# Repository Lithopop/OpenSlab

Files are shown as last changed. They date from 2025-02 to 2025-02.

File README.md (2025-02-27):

# OpenSlab
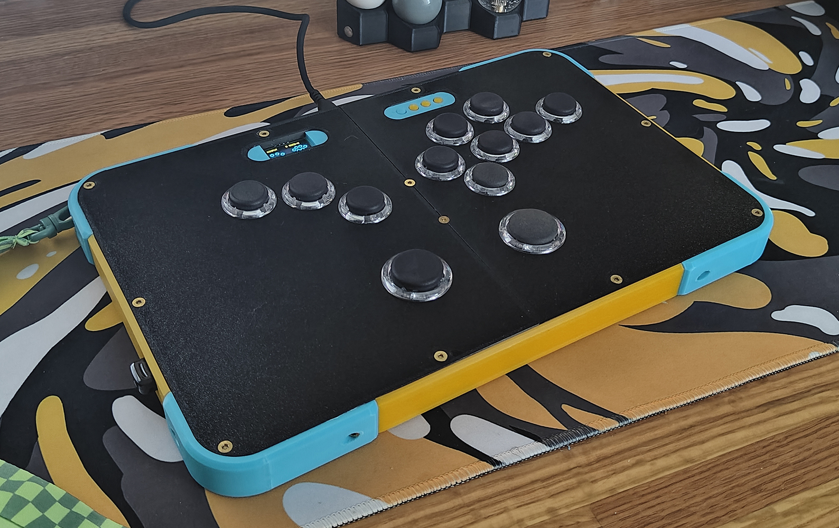
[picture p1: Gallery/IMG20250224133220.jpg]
Openslab image

flexible and rugged open source low profile leverless controller 

Openslab is an attempt to bridge the gap between the mod-ability of traditional fight sticks and the form factor of PCB based leverless designs.

Print Instructions
-----------
Frame Common Files - Mandatory files regardless of layout or plate materials. There are options for both USB C and B top walls here, and the corners are mirrored, allowing you to swap them around and put a shoulder strap or lanyard on any side, or just print 2 copies of the bottom corners if you don't want the mount points. Also note that there are arrows on the inside of all of the frame wall pieces. these should print facing up, because the top face is slightly thicker  than the bottom (4mm top, 3mm bottom) Also included is a cable cover to tidy up some wiring.

3d print plates common files - this is a collection of print files needed for a fully 3d printed leveless fight stick, that include the center brace (not part of the walls section because it's not used in acrylic builds), the assemblies f to house electronic components (gpio and display), the buttons for the GPIO which will need you to print 4 copies, and the 2 bottom panels

Fauxlix, Fauxir, Fega p2, 6 god , and 6 ERGOd top panels - A collection of layouts that will house your arcade buttons and RP2040. these are just Viewlix, Noir, Sega p2, 6 Gawd, and 6 ERGOd(my personal ergo 6 gawd format) scaled down to use primarily 24mm buttons and will use 30mm as thumb buttons. 

Plates - Cut acrylic/steel Ergod (UNTESTED) - This are just files for acrylic and steel cut parts for the tops and bottom of the fight stick, please note that this includes some 3d printed parts because the electronics housings and RP2040 mount are different. 

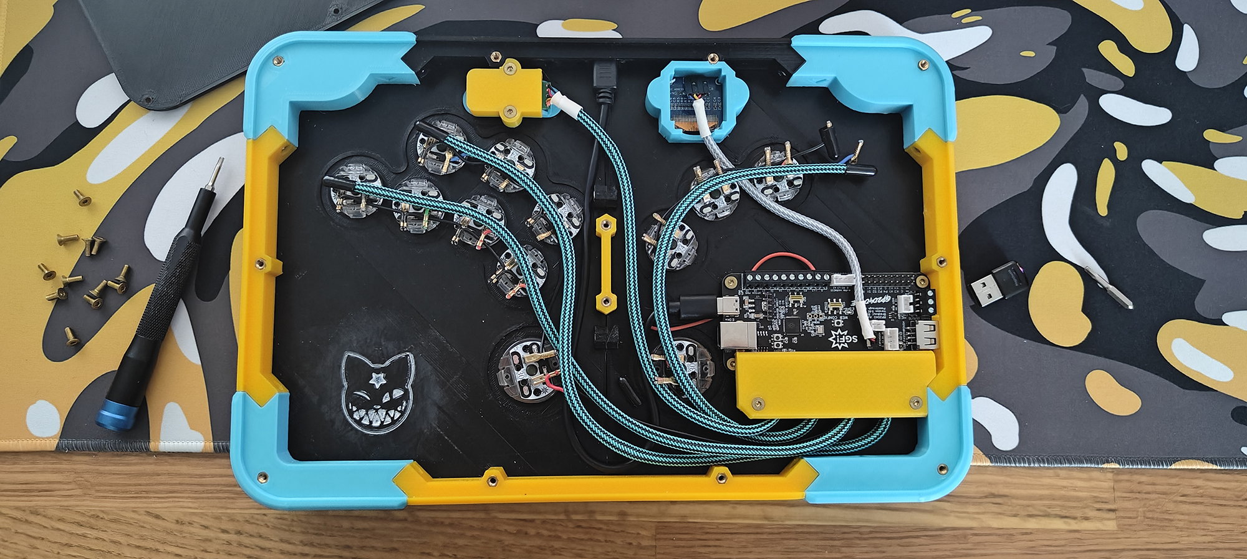
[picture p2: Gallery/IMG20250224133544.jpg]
Openslab internals


Construction process
-------------
- Build Frame
- Mount top face
- Flip upside and down insert buttons, put electronics in housings and then slot them into the top face plate (they press fit between the top and bottom faces), wire everything, add RP mount lid (cable cover)
- mount bottom plate
- set up/config RP2040
- Plug in
- enjoy?
- Give feedback (Optional)

Plexi build hardware needed/electronics needed
-----------
10 x 15mm m3 standoff

34 x 8mm flat head m3 hex 

14 x m3 nut

8 x 16mm cup head m3 hex

30 cm panel mount USB-B to 5 pin dupont or USB Type C 3.1Panel Mount Adapter Cable

Choice of low profile buttons

.96 inch Display

gpio Button Module Push Button Board

RP2040

Full 3d Print build hardware/electronics needed
-----------
12 x 15mm m3 standoff

34 x 8mm flat head m3 hex 

10 x m3 nut

8 x 16mm cup head m3 hex

30 cm panel mount USB-B to 5 pin dupont or USB Type C 3.1Panel Mount Adapter Cable

Choice of low profile buttons

.96 inch Display

gpio Button Module Push Button Board

RP2040

Electronics links
-----------
0.96 Inch OLED Module 12864 128x64 Yellow Blue SSD1306 Driver I2C Serial Self-Luminous Display Board - https://www.amazon.com/gp/product/B072Q2X2LL?ie=UTF8&psc=1 (You can probabkly find other colors, tollerances may vary this is just what I prototyped with)

Button Array Button Module Electronic Components gpio Button Module Push Button Board - https://www.amazon.com/gp/product/B0C9P8H3YZ?ie=UTF8&psc=1

Panel Mount USB 2.0 B Cable USB B Female to 5 pin Female Dupont Motherboard USB Header Cable - https://www.amazon.com/gp/product/B07DNN94JD?ie=UTF8&psc=1

USB Type C 3.1Panel Mount Adapter Cable USB-C 3.1 Gen2 10Gbps Male to USB C Female Panel Mount Screw Cable - https://www.amazon.com/gp/product/B0CCRXF1N7?ie=UTF8&psc=1

RP2040 Advanced breakout board (If you can't find one of these from a small business, what are you doing here?)

Low Profile Arcade/fightstick Buttons (Tested with Monkey Butts and Sitongs) 

Hardware links (Please note, that I used brass, you can use alternatives)
-----------
15mm m3 standoff - https://www.amazon.com/gp/product/B07H9VJ29Q?ie=UTF8&psc=1

8mm flat head m3 hex - https://www.amazon.com/gp/product/B0BP6B8CRD?ie=UTF8&th=1

m3 nut

16mm cup head m3 hex - https://www.amazon.com/gp/product/B0C7BYKWZF?ie=UTF8&th=1

While it's not necessary, Donations are always appreciated and help speed up revisions and development of other projects. (and/or farther the endeavor to push my little girl into real video games and get her away from tablet based subway surfers clones)

https://www.paypal.com/paypalme/williamthomas157

Feel free to contact me on discord with any comments, questions or suggestions.

riverbottom

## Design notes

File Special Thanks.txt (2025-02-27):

Special thanks to:

JayFree and greendusk for beta prints and testing.

InfraredAces for the fantastic idea of making my documentation "more IKEA".

Xanibunib for finding an error in my clean step file with Bottom print plate b.

OpenStickCommunity and /r/Fightsticks Discord for support and feedback.

Noblix, for the idea to eliminate the 10mm bolts.

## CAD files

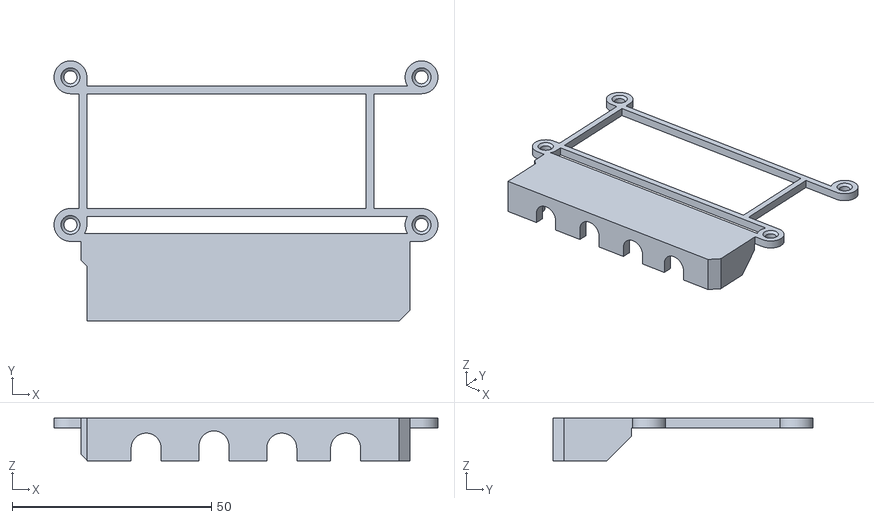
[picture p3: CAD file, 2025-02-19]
Print-Build Files/! Experimental/Acrylic Steel Plates ERGOd/RP mount.stl
96.2 x 65.2 x 10.7

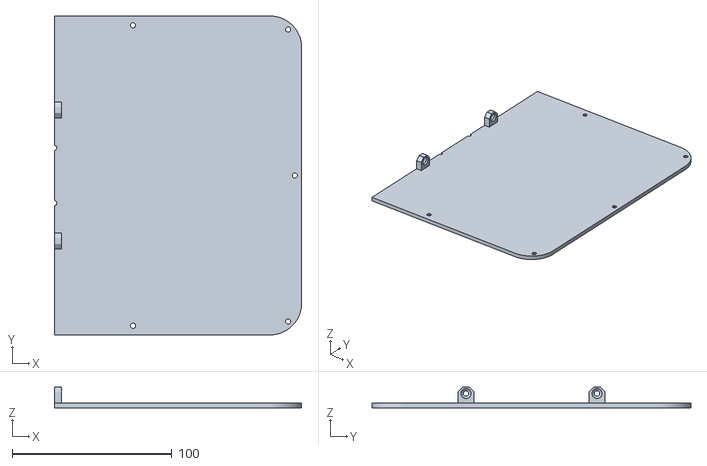
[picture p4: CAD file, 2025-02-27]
Print-Build Files/- 3D Print Plates Common Files/bottom PRINT a.stl
154.8 x 199.6 x 13.0

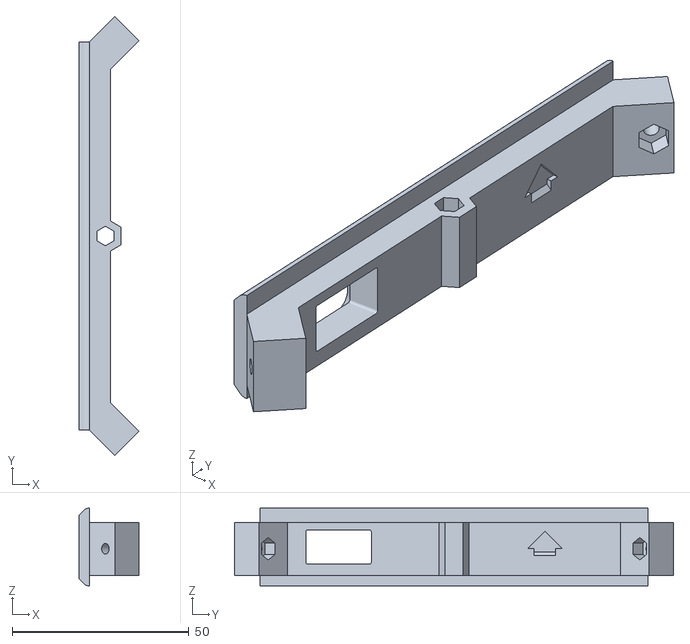
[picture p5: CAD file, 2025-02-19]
Print-Build Files/- Frame Common Files/Pass thorugh wall.stl
17.0 x 124.3 x 22.0

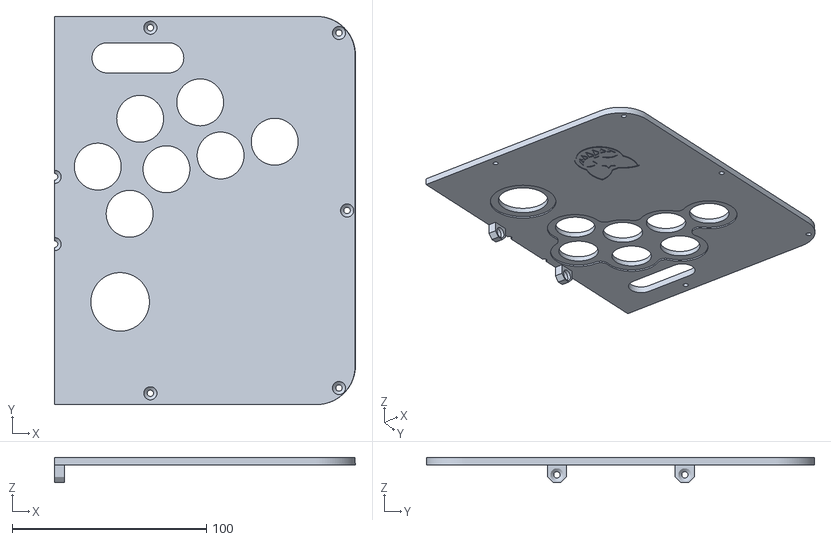
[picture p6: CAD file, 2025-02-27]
Print-Build Files/6 ERGOd/Right 6 ERGOd.stl
154.8 x 199.6 x 13.0

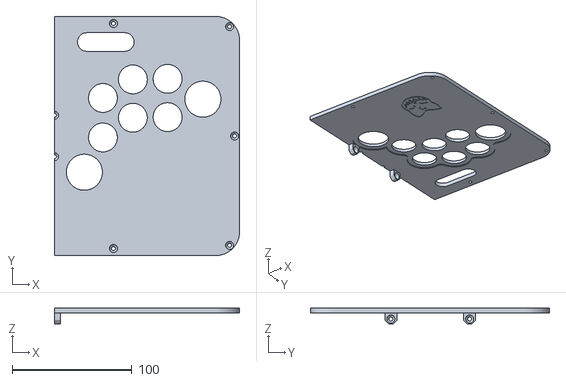
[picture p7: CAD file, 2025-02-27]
Print-Build Files/6 Fawd/Right 6 Gawd.stl
154.6 x 199.6 x 13.0

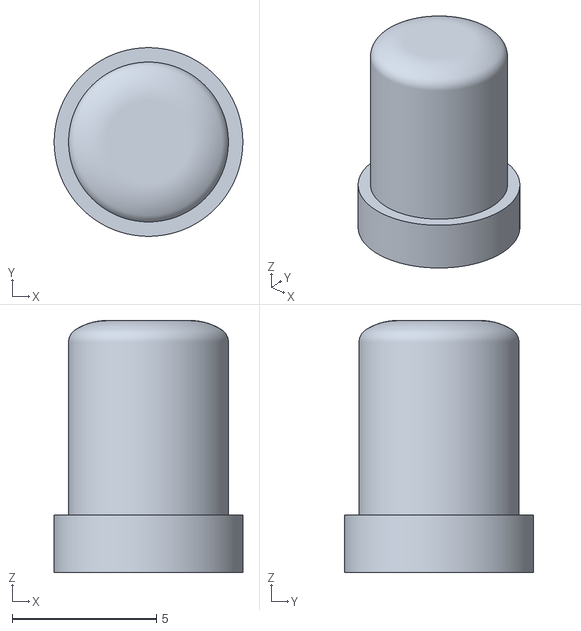
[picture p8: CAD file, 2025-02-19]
Print-Build Files/! Experimental/Acrylic Steel Plates ERGOd/button round for plexi.stl
6.55 x 6.55 x 8.75

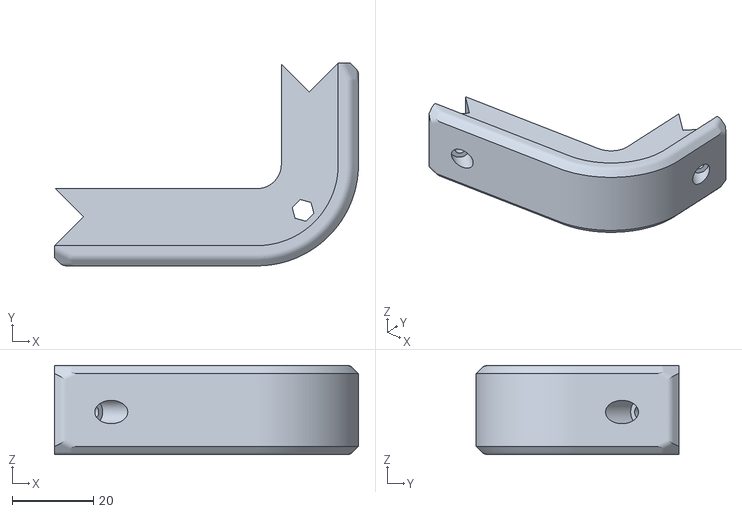
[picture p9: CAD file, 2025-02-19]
Print-Build Files/- Frame Common Files/Bottom Right Corner.stl
75.0 x 50.0 x 22.0

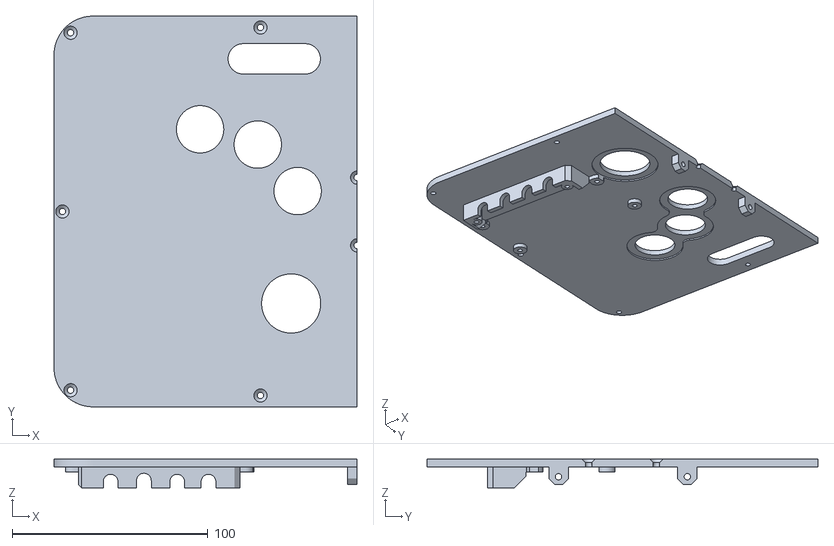
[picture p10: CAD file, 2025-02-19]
Print-Build Files/6 ERGOd/Left 6 ERGOd.stl
154.8 x 199.6 x 14.7

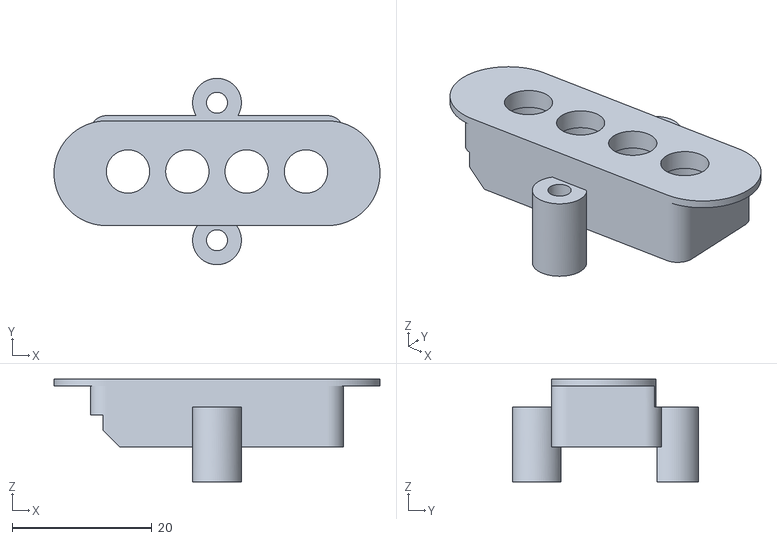
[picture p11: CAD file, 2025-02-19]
Print-Build Files/! Experimental/Acrylic Steel Plates ERGOd/aux frame top plexi.stl
46.7 x 26.7 x 14.8

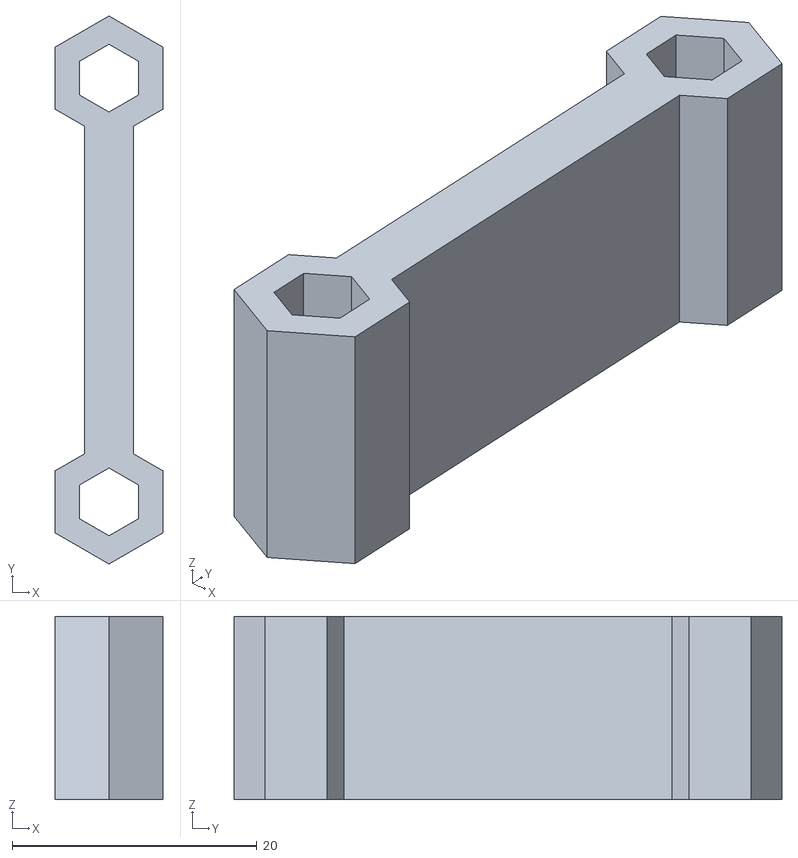
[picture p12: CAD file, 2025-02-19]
Print-Build Files/- 3D Print Plates Common Files/Mid Support.stl
8.80 x 44.8 x 15.0

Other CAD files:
Print-Build Files/Fauxir/right Fauxlir.stl
Print-Build Files/Fauxlix/right Fauxlix.stl
Print-Build Files/Fega P2/right Fega P2.stl
Print-Build Files/- 3D Print Plates Common Files/bottom PRINT b.stl
Print-Build Files/6 Fawd/Left 6 Gawd.stl
Print-Build Files/Fauxir/Left Fauxir.stl
Print-Build Files/Fauxlix/Left Fauxlix.stl
Print-Build Files/Fega P2/Left Fega P2.stl
Print-Build Files/! Experimental/Acrylic Steel Plates ERGOd/Screen holder.stl
Print-Build Files/! Experimental/Acrylic Steel Plates ERGOd/Steel Top.stl
Print-Build Files/! Experimental/Acrylic Steel Plates ERGOd/aux frame bottom plexi.stl
Print-Build Files/! Experimental/Acrylic Steel Plates ERGOd/bottom plexi.stl
Print-Build Files/! Experimental/Acrylic Steel Plates ERGOd/plexi Top.stl
Print-Build Files/- 3D Print Plates Common Files/Screen holder.stl
Print-Build Files/- 3D Print Plates Common Files/aux frame bottom.stl
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

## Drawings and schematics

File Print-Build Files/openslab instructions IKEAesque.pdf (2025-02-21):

1

2

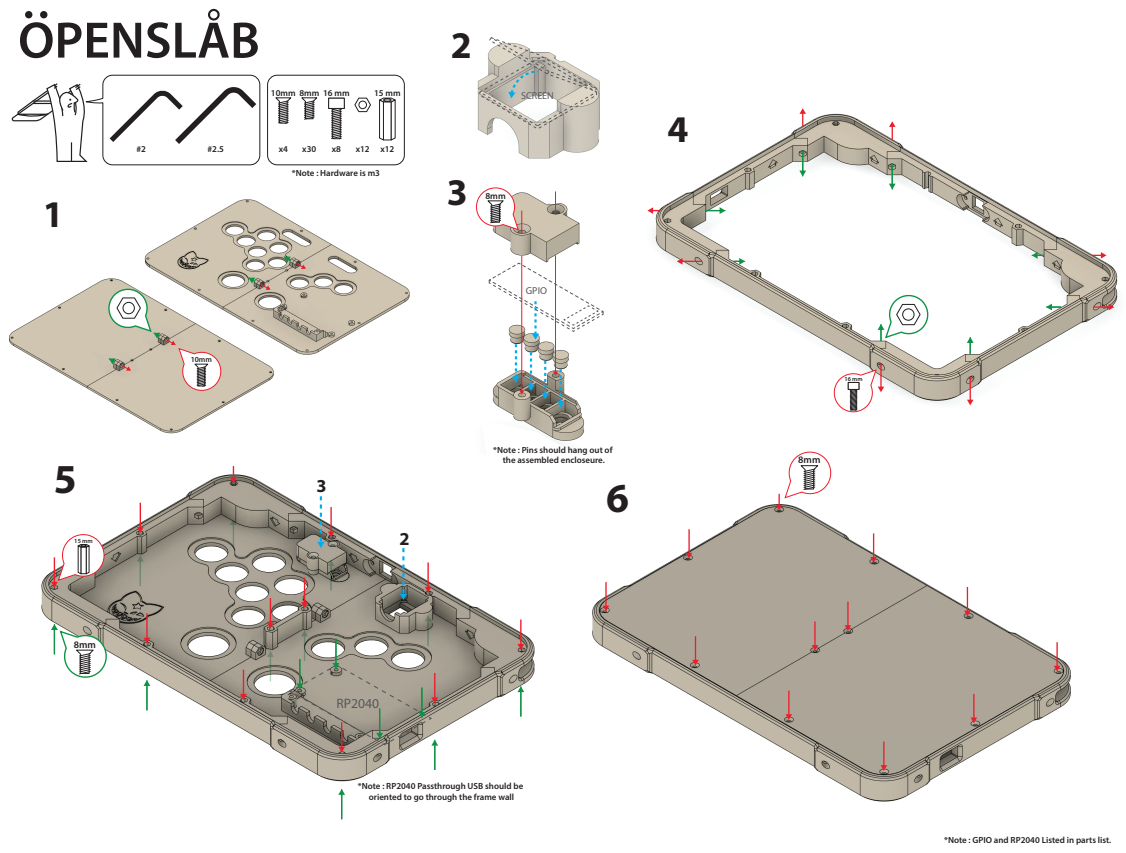
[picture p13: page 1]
SCREEN; OPENSLAB 10mm 8mm; GPIO

*Note : Hardware is m3

*Note : Pins should hang out of
the assembled encloseure.

*Note : RP2040 Passthrough USB should be
oriented to go through the frame wall

*Note : GPIO and RP2040 Listed in parts list.

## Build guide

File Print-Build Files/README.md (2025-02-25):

# OpenSlab
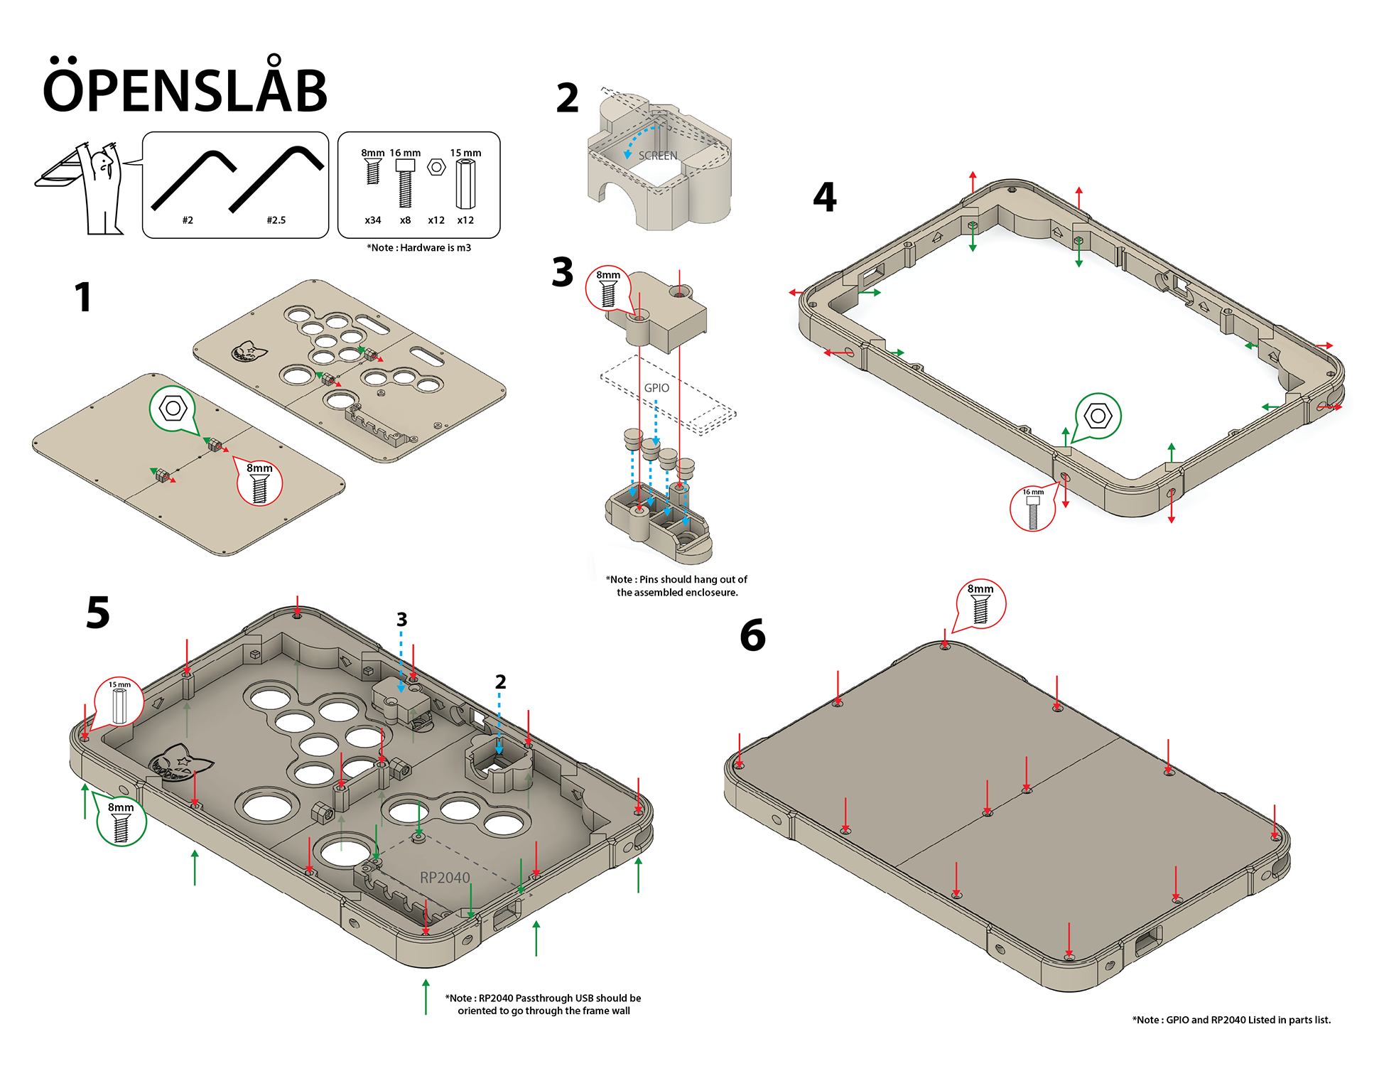
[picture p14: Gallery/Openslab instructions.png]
Openslab exploded


Print Instructions
-----------
Frame Common Files - Mandatory files regardless of layout or plate materials. There are options for both USB C and B top walls here, and the corners are mirrored, allowing you to swap them around and put a shoulder strap or lanyard on any side, or just print 2 copies of the bottom corners if you don't want the mount points. Also note that there are arrows on the inside of all of the frame wall pieces. these should print facing up, because the top face is slightly thicker  than the bottom (4mm top, 3mm bottom) Also included is a cable cover to tidy up some wiring.

3d print plates common files - this is a collection of print files needed for a fully 3d printed leveless fight stick, that include the center brace (not part of the walls section because it's not used in acrylic builds), the assemblies f to house electronic components (gpio and display), the buttons for the GPIO which will need you to print 4 copies, and the 2 bottom panels

Fauxlix, Fauxir, Fega p2, 6 god , and 6 ERGOd top panels - A collection of layouts that will house your arcade buttons and RP2040. these are just Viewlix, Noir, Sega p2, 6 Gawd, and 6 ERGOd(my personal ergo 6 gawd format) scaled down to use primarily 24mm buttons and will use 30mm as thumb buttons. 

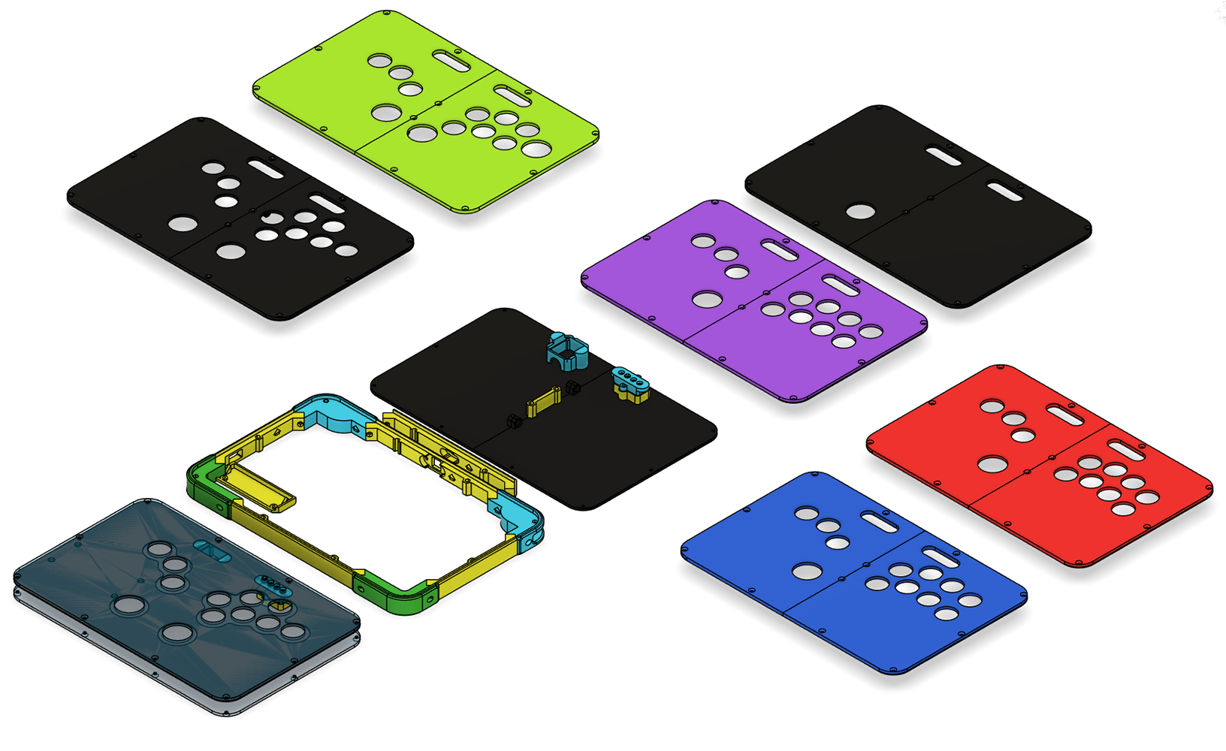
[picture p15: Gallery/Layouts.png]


Plates - Cut acrylic/steel Ergod (UNTESTED) - This are just files for acrylic and steel cut parts for the tops and bottom of the fight stick, please note that this includes some 3d printed parts because the electronics housings and RP2040 mount are different.

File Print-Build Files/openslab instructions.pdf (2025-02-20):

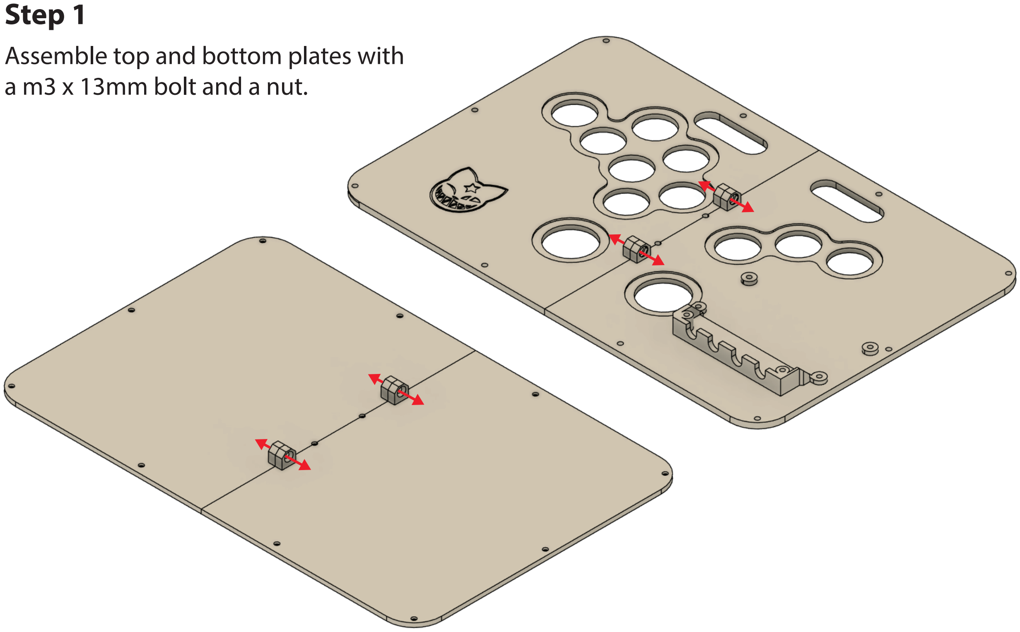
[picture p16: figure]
Step 1 Assemble top and bottom plates with a m3 x 13mm bolt and a nut.

### Step 2

### Step 3

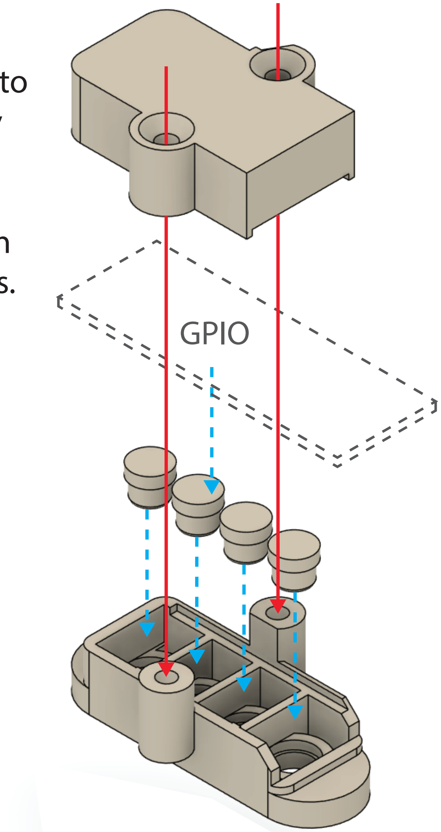
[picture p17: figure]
GPIO

Insert the buttons into
the button assembly
top, then sandwich
the GPIO board and
fasten the bottom on
with m3 x 8mm bolts.

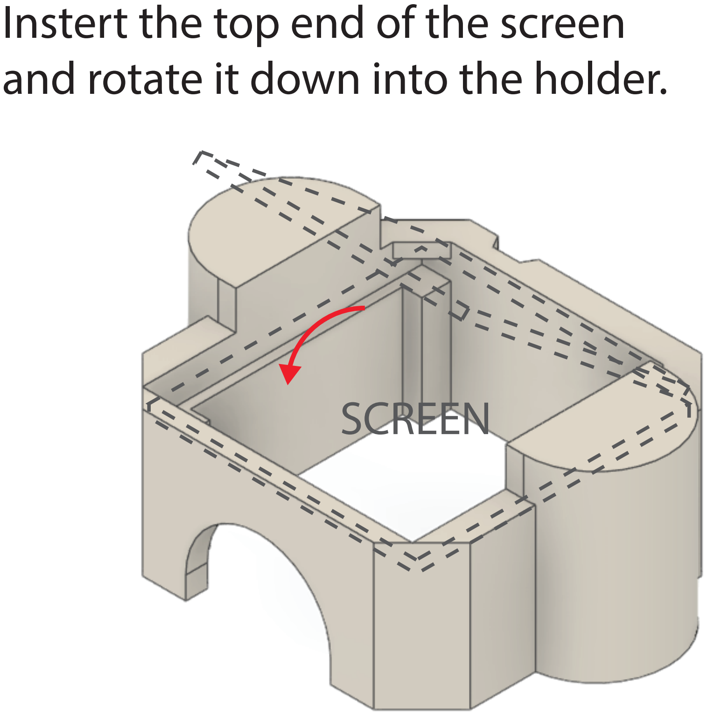
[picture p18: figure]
SCREEN; Instert the top end of the screen and rotate it down into the holder.

### Step 4

Assemble the frame with m3 x 16 cup head bolts

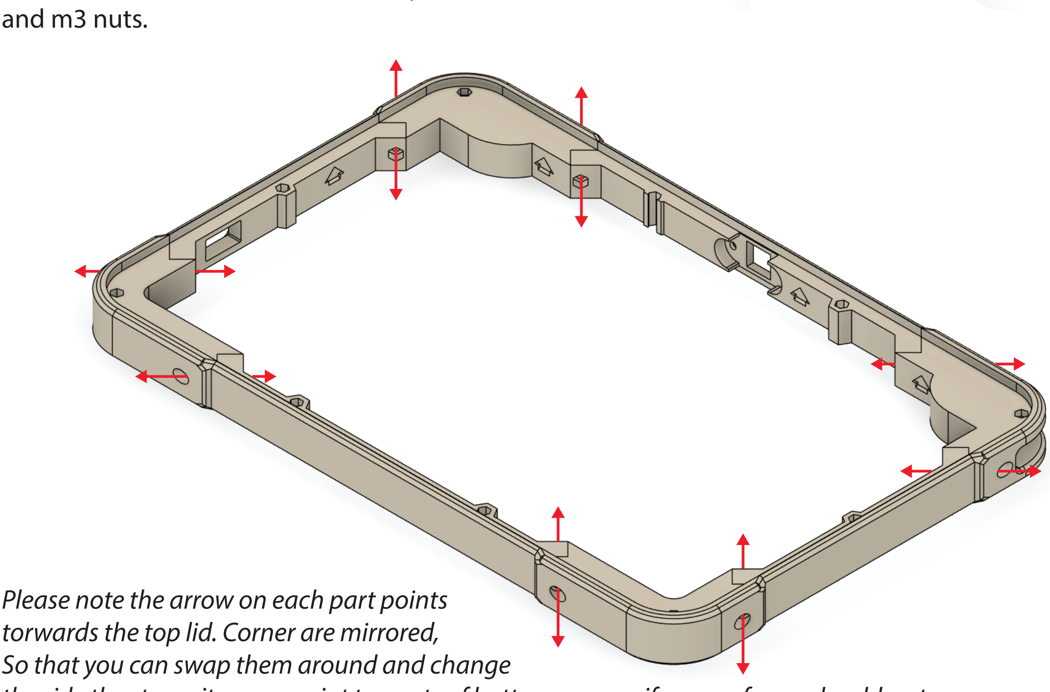
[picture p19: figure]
and m3 nuts.

### Step 5

Insert 15mm m3 stand-os and bolt the top face on with m3 x 8mm bolts. You may then Add in the Screen and GPIO. They just slot in and are held in place once the back is bolted on.

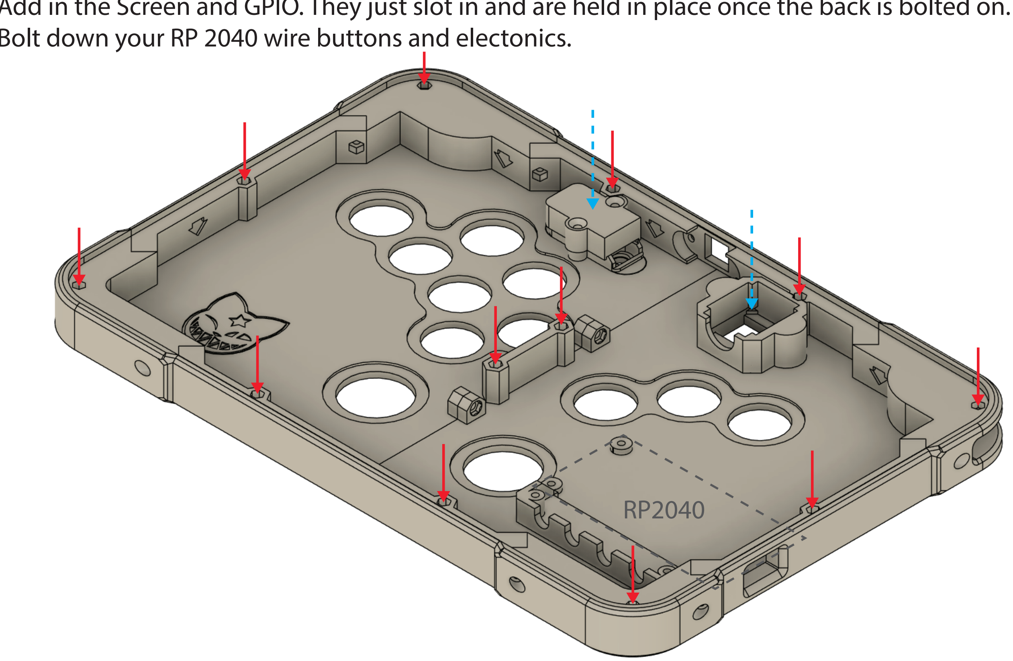
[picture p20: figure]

Bolt down your RP 2040 wire buttons and electonics.

Please note the arrow on each part points
torwards the top lid. Corner are mirrored,
So that you can swap them around and change
the side the strap sits on, or print two sets of bottom corners if you prefer no shoulder stap.

### Step 6

Bolt on bottom plate with m3 x 8 bolts. You may now clip on a sholder strap around the m3 stand-osthat are exposed on the top corners if you used them. Assembly is done.

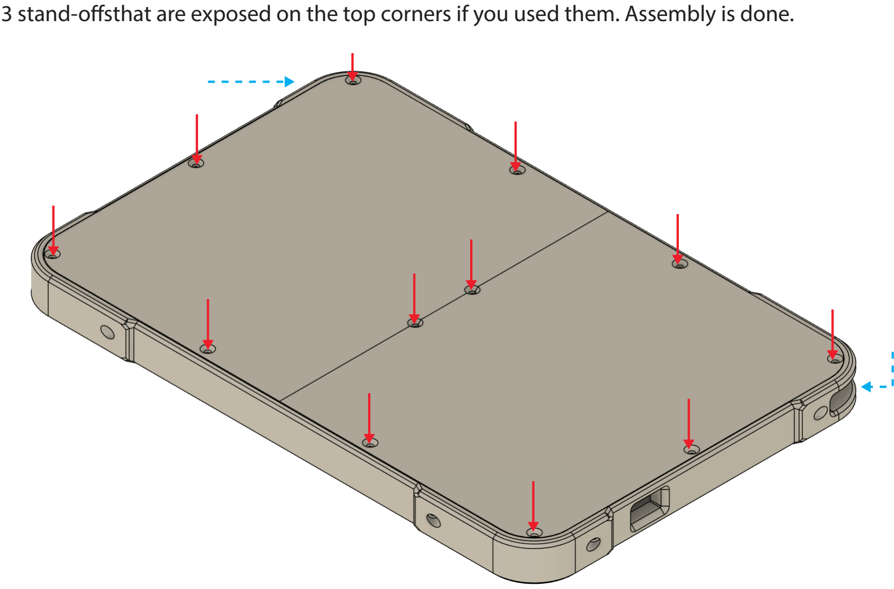
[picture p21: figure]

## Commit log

2025-02-19 update of core files
    [Bottom Left Corner.stl, Bottom Right Corner.stl, Left 6 ERGOd.stl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]
2025-02-19 Rebuilding heirarchy
    [Bottom Left Corner.stl, Bottom Right Corner.stl, Left 6 ERGOd.stl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]
2025-02-20 Heirarchy cleanup/Documentation
    [Bottom Left Corner.stl, Bottom Right Corner.stl, Left Fauxir.stl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]
2025-02-21 error in bottom plate b
    [bottom PRINT b.stl]
2025-02-27 v1.1 (removed 10mm bolts)
    [Right 6 ERGOd.stl, Right 6 Gawd.stl, bottom PRINT a.stl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]
